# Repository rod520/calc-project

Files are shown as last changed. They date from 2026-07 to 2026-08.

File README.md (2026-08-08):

# Pico Calc electronics design
### the electronics portion of an rpi Pico based calculator
## BOM:
| Part name | notes | Qty | Link |
| --- | --- | --- | --- |
| 3.2inch SPI Module ILI9341 SKU:MSP3217 | 3218 will also work as touchscreen is not wired | 1 | https://www.amazon.com/Pasuihcay-240X320-ILI9341-Occupies-MSP3218/dp/B0D5YFC594 |
| 6mm tactile switch |  | 36 | https://www.amazon.com/QTEATAK-Momentary-Tactile-Button-Switch/dp/B07VSNN9S2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 |
| Pimoroni lipo pico | Note: pico 2 lipo will also work | 1 | https://vilros.com/products/pimoroni-pico-lipo-16mb |
| Lithium Ion Battery - 3.7V 2000mAh | Note: any battery with/connected to a JST-PH connector will work | 1 | https://www.adafruit.com/product/2011 |
| short plug male header | for pico, normal sized header pins and socket will work as well | 2 | https://www.adafruit.com/product/5584 |
| Short Socket Headers | see above | 2 | https://www.adafruit.com/product/5585 |

## design:
The pcb consists of two separated sections, the button matrix and the display connection, connected to an rpi with headers through 2 through hole pin connectors. Buttons are 6mm through hole, display is an MSP321**7** (no touch screen), connector is 1x20 2.54mm. 
**IMPORTANT:** the male header pins should be pointed down for access to bootsel, and the pico's usb port should be pointed outside, to the right if viewed from above.
## software:
see [zig-calc](https://github.com/rod520/zig-calc) for software, and also button overlay.

## WHY?
I wanted to make a clone of the numworks calculator, but I realized that wasnt feasible and cheap, so I eventually landed on making a pi-hat like extension for an rpi pico. The pico clone Pimoroni LiPo Pico can connect to  an optional Lithium Ion Battery, so this calculator will (eventually) have nearly every feature of the numworks, albeit with a vertical display, thicker case, and cheap clicky buttons. 

## materials:
1. 36 6mm through hole tactile buttons
2. 2 1x20 female/socket connectors, **2.54 mm**, I'm planning on using Adafruit's short socket headers
3. 2 matching 1x20 male/pin connectors, **2.54 mm**, I'm planning on using Adafruit's short pin headers, or you can stick with the pico's default
4. MSP3217 or MSP3218, both work, but you will not be able to use the MSP3218's touchscreen
5. soldering materials
6. an rpi pico, with headers facing down, (OPTIONAL) pimoroni lipo pico in case you want to use a rechargeable battery
7. (OPTIONAL) a JST-PH battery for the pimoroni lipo pico


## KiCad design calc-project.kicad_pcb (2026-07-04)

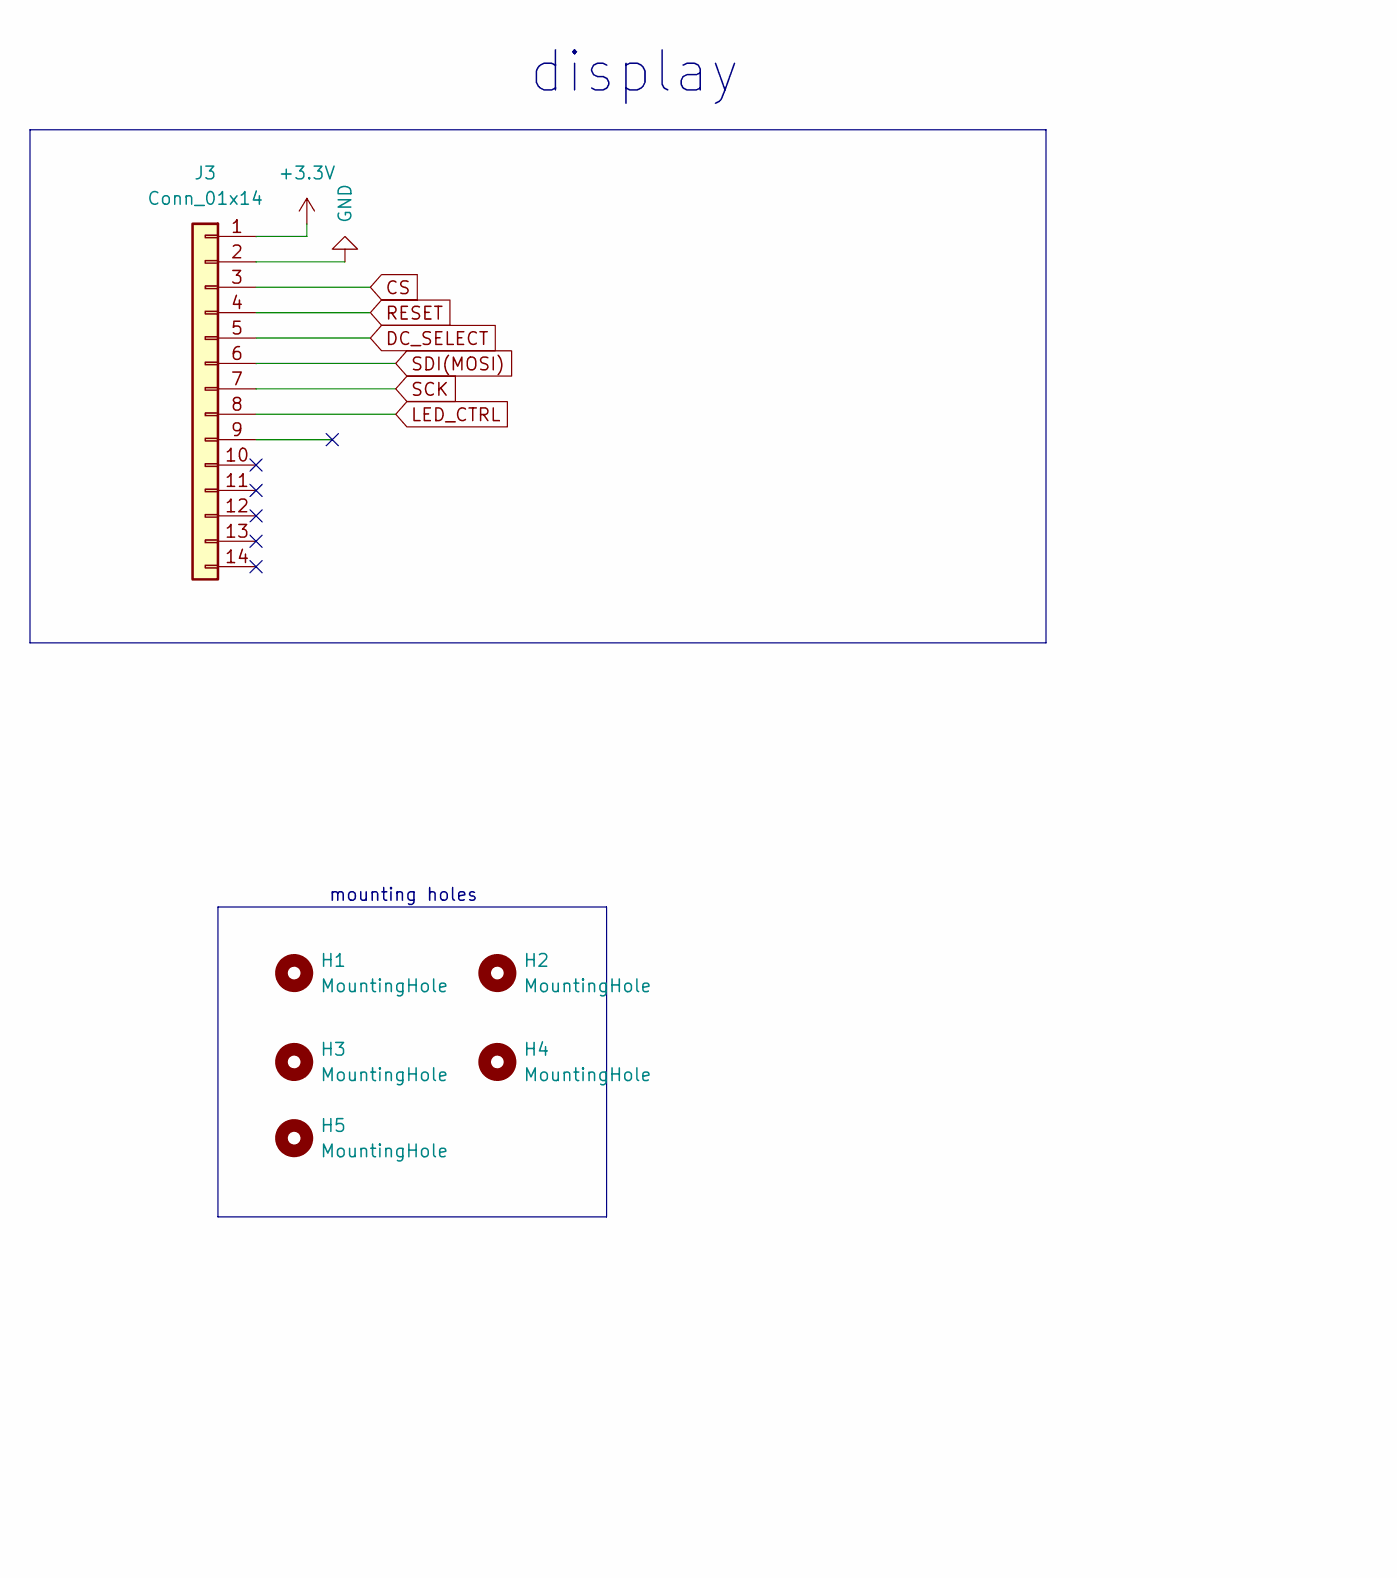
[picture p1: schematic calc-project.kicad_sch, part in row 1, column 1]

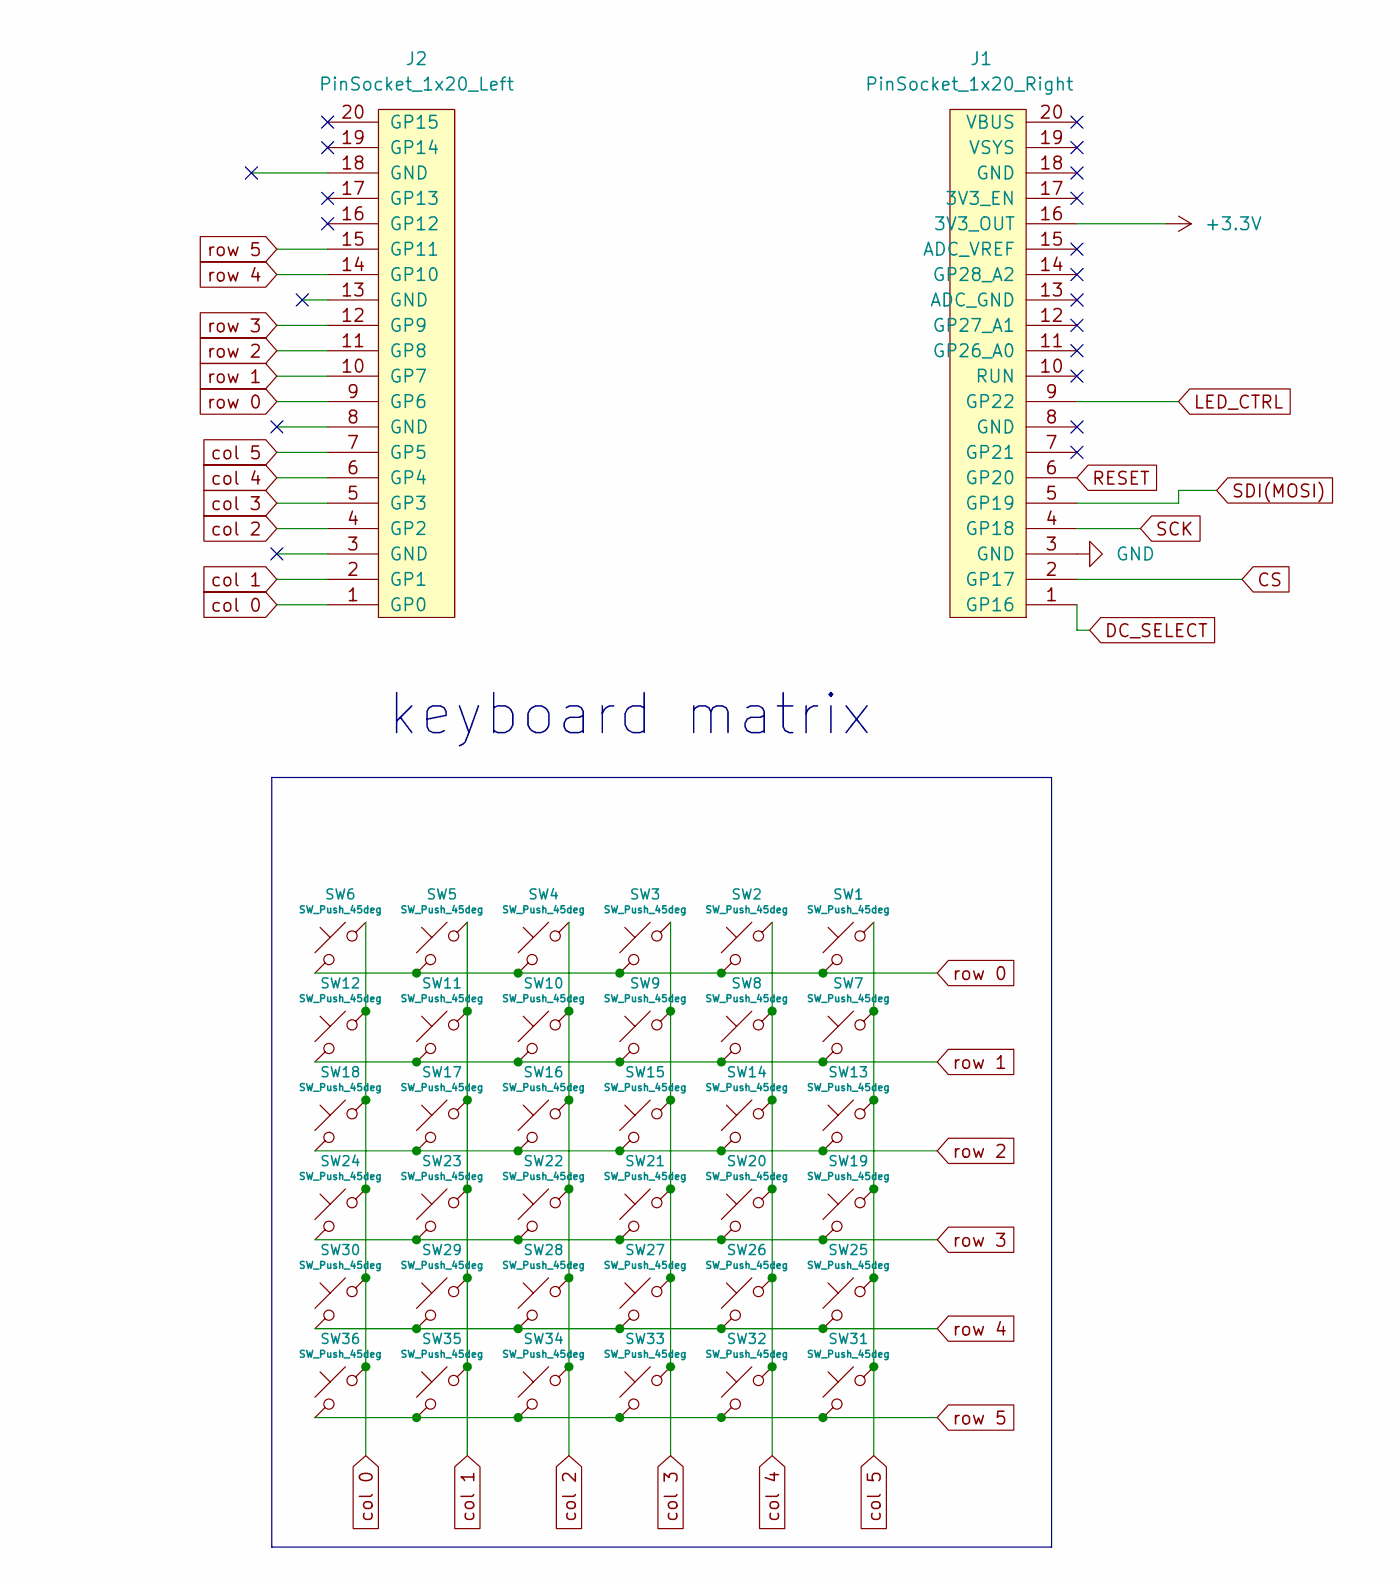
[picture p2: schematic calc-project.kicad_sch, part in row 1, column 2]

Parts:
H1, H2, H3, H4, H5: MountingHole; MountingHole_2.1mm
J1: PinSocket_1x20_Right; PinSocket_1x20_P2.54mm_Vertical
J2: PinSocket_1x20_Left; PinSocket_1x20_P2.54mm_Vertical
J3: Conn_01x14; castel_toScreen
SW1, SW2, SW3, SW4, SW5, SW6, SW7, SW8, SW9, SW10, SW11, SW12, SW13, SW14, SW15, SW16, SW17, SW18, SW19, SW20, SW21, SW22, SW23, SW24, SW25, SW26, SW27, SW28, SW29, SW30, SW31, SW32, SW33, SW34, SW35, SW36: SW_Push_45deg; SW_PUSH_6mm_centered

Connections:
+3.3V: J1.16 (3V3_OUT), J3.1
CS: J1.2 (GP17), J3.3
DC_SELECT: J1.1 (GP16), J3.5
GND: J1.3 (GND), J3.2
LED_CTRL: J1.9 (GP22), J3.8
RESET: J1.6 (GP20), J3.4
SCK: J1.4 (GP18), J3.7
SDI(MOSI): J1.5 (GP19), J3.6
col 0: J2.1 (GP0), SW6.1, SW12.1, SW18.1, SW24.1, SW30.1, SW36.1
col 1: J2.2 (GP1), SW5.1, SW11.1, SW17.1, SW23.1, SW29.1, SW35.1
col 2: J2.4 (GP2), SW4.1, SW10.1, SW16.1, SW22.1, SW28.1, SW34.1
col 3: J2.5 (GP3), SW3.1, SW9.1, SW15.1, SW21.1, SW27.1, SW33.1
col 4: J2.6 (GP4), SW2.1, SW8.1, SW14.1, SW20.1, SW26.1, SW32.1
col 5: J2.7 (GP5), SW1.1, SW7.1, SW13.1, SW19.1, SW25.1, SW31.1
row 0: J2.9 (GP6), SW1.2, SW2.2, SW3.2, SW4.2, SW5.2, SW6.2
row 1: J2.10 (GP7), SW7.2, SW8.2, SW9.2, SW10.2, SW11.2, SW12.2
row 2: J2.11 (GP8), SW13.2, SW14.2, SW15.2, SW16.2, SW17.2, SW18.2
row 3: J2.12 (GP9), SW19.2, SW20.2, SW21.2, SW22.2, SW23.2, SW24.2
row 4: J2.14 (GP10), SW25.2, SW26.2, SW27.2, SW28.2, SW29.2, SW30.2
row 5: J2.15 (GP11), SW31.2, SW32.2, SW33.2, SW34.2, SW35.2, SW36.2

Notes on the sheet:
display
keyboard matrix
mounting holes

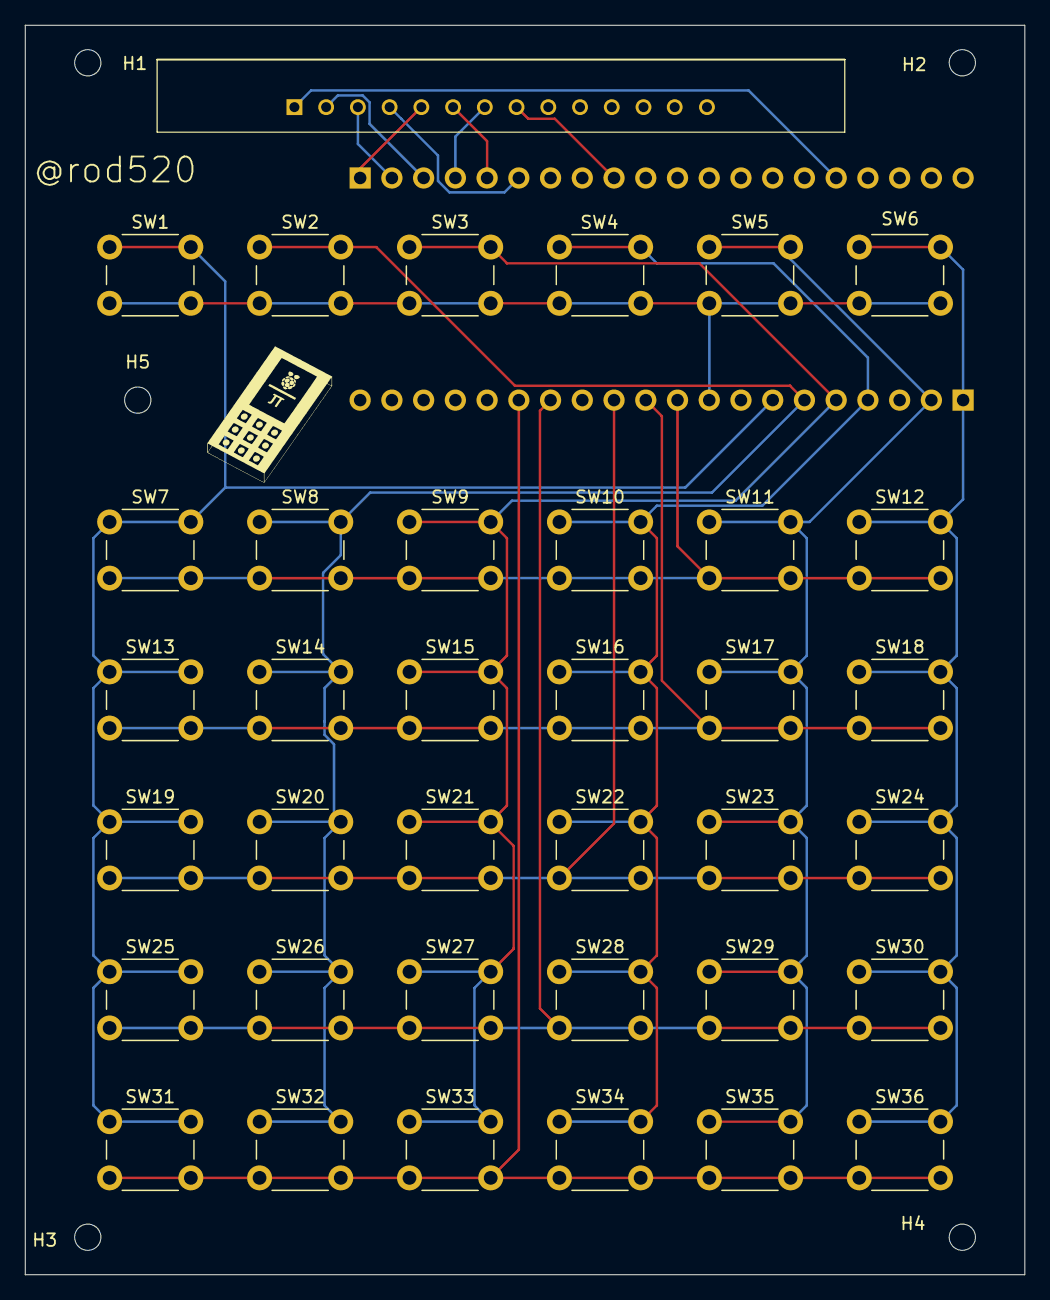
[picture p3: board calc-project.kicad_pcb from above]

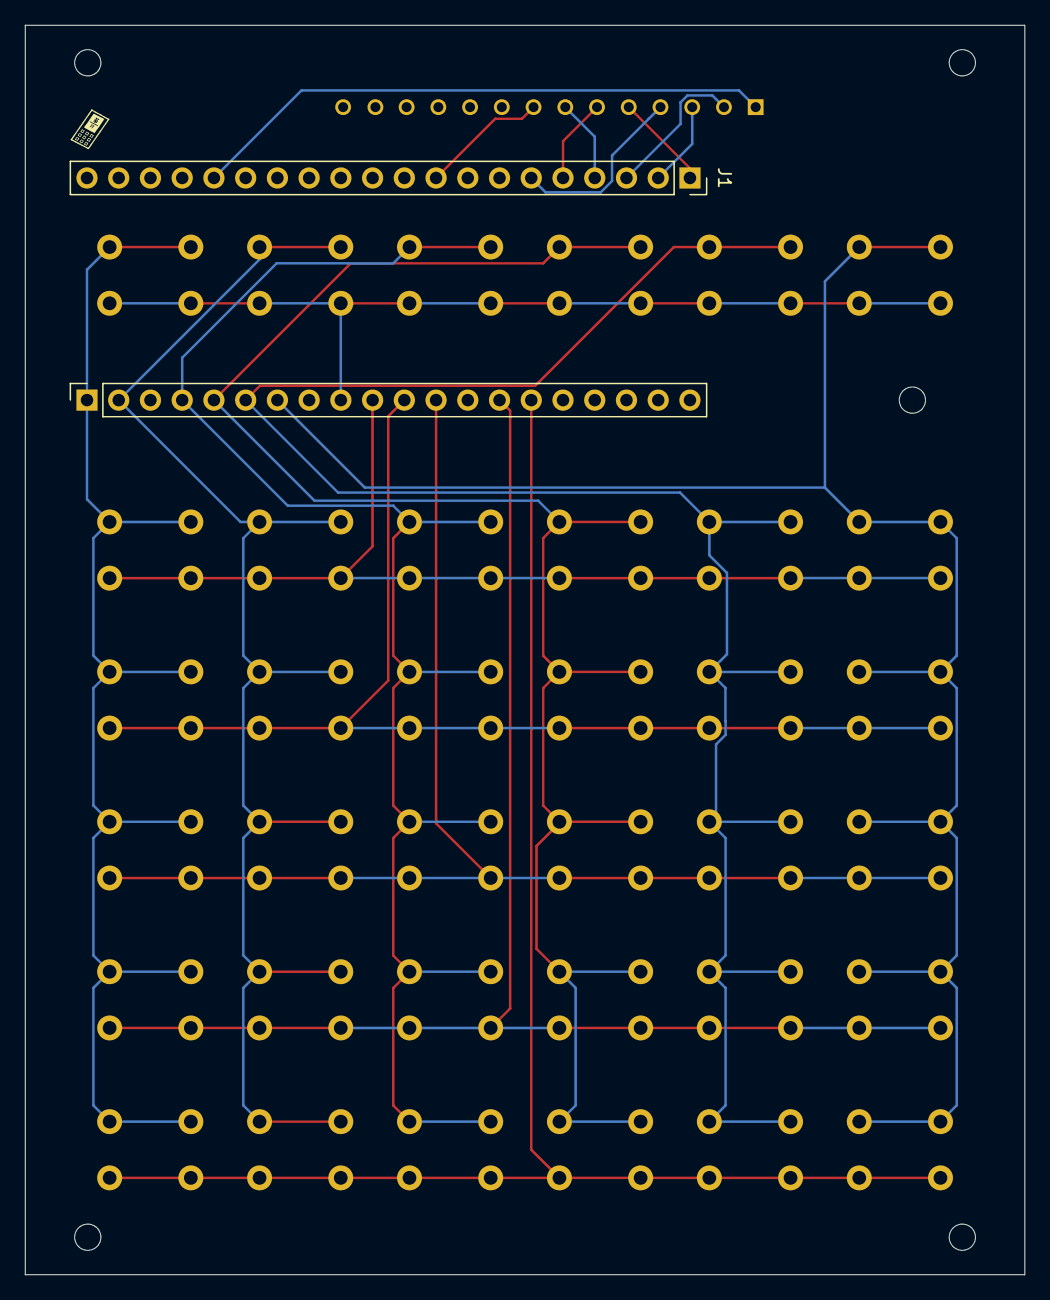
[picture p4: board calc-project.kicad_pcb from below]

Board: 2 copper layers, 80.0 x 100.0 mm, 44 parts (2 on the bottom side), 20 nets.

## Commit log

2026-06-04 added rpi pico, took away connectors, idk what else
    idk what i did
    [calc-project.kicad_pcb, calc-project.kicad_sch]
2026-06-05 idek if this is progress or not
    [calc-project.kicad_sch]
2026-06-09 we're now setting ourselves up for new screen, still need alignment
    [calc-project.kicad_pcb, calc-project.kicad_sch]
2026-06-09 fixed names, seems like schematic is good
    [calc-project.kicad_pcb, calc-project.kicad_sch]
2026-06-16 edited some stuff
    fixed footprint, wired up, moved screen
    [calc-project.kicad_pcb, calc-project.kicad_sch]
2026-06-22 routing
    routing
    [calc-project.kicad_pcb, calc-project.kicad_sch]
2026-06-22 capabilities
    yeah
    did use kicad happy just to check and make sure we had capabilities
    [calc-project.kicad_pcb, calc-project.kicad_sch]
2026-06-22 wrong pin
    [calc-project.kicad_pcb, calc-project.kicad_sch]
2026-06-23 random stuff, i think it helps
    [calc-project.kicad_pcb, calc-project.kicad_sch]
2026-06-23 better dimensions
    Didn't have to be so wide, so I put all the components closer together and rerouted the whole thing
    [calc-project.kicad_pcb]
2026-06-24 one last change
    [calc-project.kicad_pcb]
2026-06-25 created gerbers, added logo
    [calc-project-B_Cu.gbr, calc-project-B_Mask.gbr, calc-project-B_Paste.gbr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]
2026-06-25 idek what just happened
    but im trusting its fine
    [calc-project.kicad_pcb]
2026-06-25 Delete 3dComponents/FH12S-40S-0.5SH(55)_CL0586-0640-0-55_3DDrawing_STEP_0001219161S(connector) directory
    whoops wasn't actually supposed to leave that there
    [FH12S-40S-0.5SH.stp]
2026-06-25 Delete 3dComponents/TL3315NF160Q(switch) directory
    this is the wrong switch anyway
    [TL3315NF160Q.step]
2026-06-26 replaced old headers, now new ones
    also took out routing for rows
    [calc-project.kicad_pcb, calc-project.kicad_sch]
2026-06-26 BOM
    bill of materials
    [BOM.csv]
2026-06-26 Revise README sections and update materials list
    Updated hardware section to mechanical and added details about materials.
2026-07-04 mb one last connection
    [calc-project.kicad_pcb]
2026-07-07 camera+kalidokit working
    still not wired to our character yet, thats the next step
    [calc-project-B_Cu.gbr, calc-project-B_Mask.gbr, calc-project-B_Paste.gbr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]
2026-08-03 edit md
    Added software reference and removed battery item.
